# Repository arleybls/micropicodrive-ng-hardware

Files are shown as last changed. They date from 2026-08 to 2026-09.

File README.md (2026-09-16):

# MicroPicoDrive NG — Hardware

KiCad hardware design for an internal Microdrive replacement for the Sinclair QL. The device emulates a Microdrive cartridge drive using a Raspberry Pi Pico (RP2040) and stores data on a microSD card, fitting in the QL's internal Microdrive bay.

This is an evolution of [gusmanb/micropicodrive](https://github.com/gusmanb/micropicodrive) by Agustín Gimenez Bernad, who reverse-engineered the Microdrive protocol and created the original design. All credit for the core concept and the main board design goes to him.

This repository contains only the hardware. The firmware lives in a separate repository: [micropicodrive-ng-firmware](https://github.com/arleybls/micropicodrive-ng-firmware).

Fitting the board inside a QL — including the Pico and the optional vibration motor — is covered by the [hardware installation manual](docs/HARDWARE_INSTALLATION_MANUAL.md) ([PDF](docs/HARDWARE_INSTALLATION_MANUAL.pdf)). Day-to-day use, SD cards and firmware updates are in the firmware repository's manual.

## What changed in this version

The cartridge board was redesigned around a different user-interface module:

- The I²C SSD1306 OLED was replaced with a 0.96" 80×160 IPS colour display (ST7735S, 4-wire SPI) with four integrated pushbuttons (K1–K4).
- A fourth button and a blinking activity LED were added; the three separate status LEDs were removed.
- The display reset uses a passive RC circuit on the cartridge and the backlight is tied to +3.3V, so the 16-pin edge connector still carries everything with no pins to spare.

The main board is essentially the original MicroPicoDrive design, updated to KiCad 10 format with the edge-connector pinout changes required by the new cartridge.

## Boards

| Board | Folder | Description |
|---|---|---|
| MicroPicoDrive | [MicroPicoDrive/](MicroPicoDrive/) | Main controller board: Raspberry Pi Pico, 5V regulation, level shifters (SN74LVC1T45 ×2, TXU0304), QL Microdrive bus header, edge connector to the cartridge |
| MicroPicoDriveCartridge | [MicroPicoDriveCartridge/](MicroPicoDriveCartridge/) | Cartridge board: microSD socket, ST7735S SPI display with 4 buttons, activity LED, 16-pin edge connector |

Both projects are in KiCad 10 format. Custom symbol and footprint libraries are included alongside each project and referenced with relative paths, so the projects open without extra library setup.

## Assembled boards

Cartridge (left) and main board (right), front side — the cartridge's ST7735S display with the K1–K4 buttons, and the main board's level shifters, cartridge edge-connector slot, and ribbon cable to the QL:

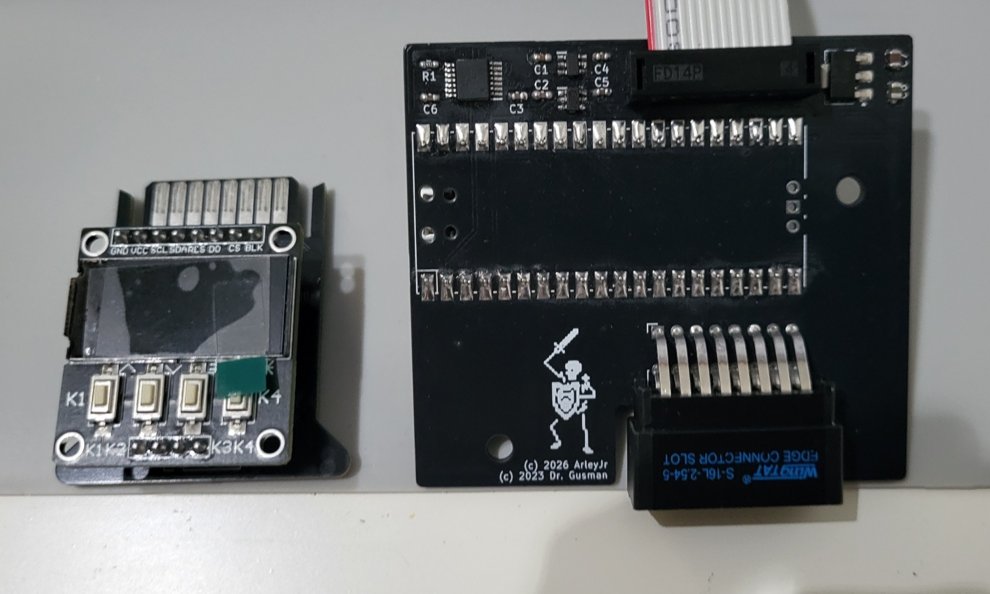
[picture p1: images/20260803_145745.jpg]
Cartridge and main board, front side


Back side — the cartridge's microSD socket, and the main board with the Raspberry Pi Pico mounted and the motor connector:

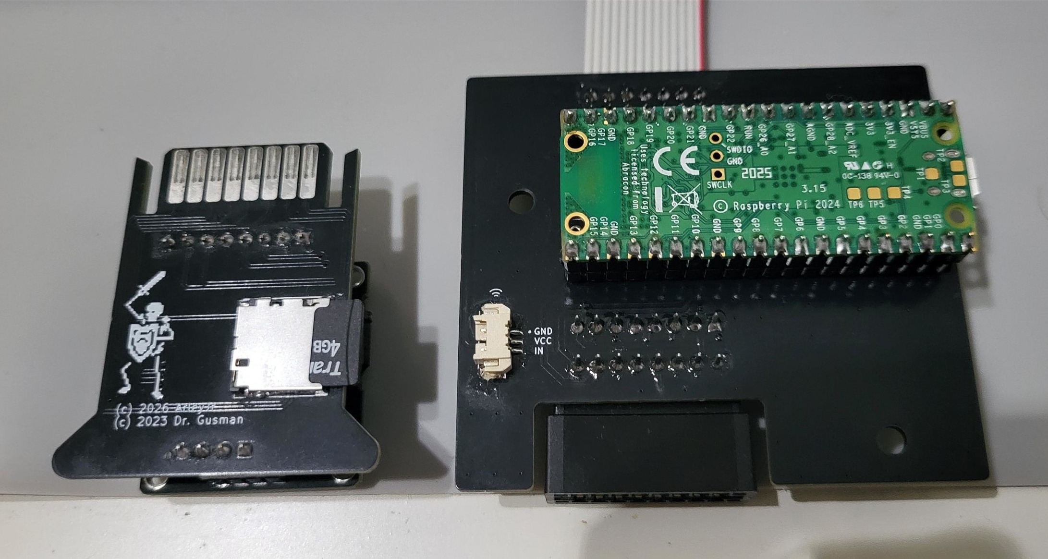
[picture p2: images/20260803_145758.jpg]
Cartridge and main board, back side


## Hot-swap guarding

The cartridge can be inserted and removed while the QL is powered, so the edge-connector fingers are staggered to enforce a safe mating order:

- **GND (pin 3) and UI_DETECT (pin 14)** are full length and make contact first. UI_DETECT is tied to GND on the cartridge, so it doubles as a second early ground contact on the opposite face of the board — a tilted insertion finds ground first on either face.
- **+3V3 (pin 1)** is retracted 1 mm and connects second.
- **All signal fingers** are retracted 1.75 mm and connect last, once the cartridge is already referenced and powered. On removal the order reverses: the signals break first while the board still has power, so an interrupted transfer fails cleanly instead of back-powering the display and SD card through their protection diodes.

UI_DETECT is read by the main board (GPIO 15, low = cartridge present). The firmware side of the guard — debouncing the detect signal on insertion before initialising the display and SD card, and tri-stating all cartridge signals on removal — is handled in [micropicodrive-ng-firmware](https://github.com/arleybls/micropicodrive-ng-firmware).

## Fabrication

Gerber and drill files are included for both boards:

- Main board: [MicroPicoDrive/gerbers/](MicroPicoDrive/gerbers/)
- Cartridge: [MicroPicoDriveCartridge/gerbers/](MicroPicoDriveCartridge/gerbers/)

A ready-to-upload JLCPCB package for the main board (Gerbers, BOM and pick-and-place for the SMD parts, with ordering notes) is in [MicroPicoDrive/jlcpcb/](MicroPicoDrive/jlcpcb/).

## Bill of materials

Interactive HTML BOMs are provided per board:

- Main board: [MicroPicoDrive/bom/ibom.html](MicroPicoDrive/bom/ibom.html)
- Cartridge: [MicroPicoDriveCartridge/bom/ibom.html](MicroPicoDriveCartridge/bom/ibom.html)

## Credits

- Original MicroPicoDrive hardware, firmware, and Microdrive protocol reverse engineering: [Agustín Gimenez Bernad (gusmanb)](https://github.com/gusmanb)
- SPI display / 4-button cartridge redesign: Arley Silveira

## License

MIT — see [LICENSE](LICENSE). The license retains the original author's copyright notice alongside the notice for the modifications in this repository.

## Related repositories

- [micropicodrive-ng-firmware](https://github.com/arleybls/micropicodrive-ng-firmware) — the firmware that brings these boards to life. It runs on the Pico mounted on the main board and answers the QL's Microdrive bus in real time, serving cartridge images from the microSD card with a menu-driven UI on the cartridge's colour display. Two builds are available: Lite for the standard Pico (RP2040) and Full for the Pico 2 W (RP2350) with Bluetooth and wireless firmware updates. Flash it to the assembled hardware and the QL sees a real Microdrive.
- [sinclair-mdv-builder](https://github.com/arleybls/sinclair-mdv-builder) — a Windows desktop tool (.NET 8 / WPF) to create, inspect, edit, and extract Sinclair QL Microdrive images (`.MDV`). Use it to author or modify cartridge images on your PC — importing files or ZIP archives while preserving QL file metadata — then copy them to the microSD card for this drive to serve to the QL.

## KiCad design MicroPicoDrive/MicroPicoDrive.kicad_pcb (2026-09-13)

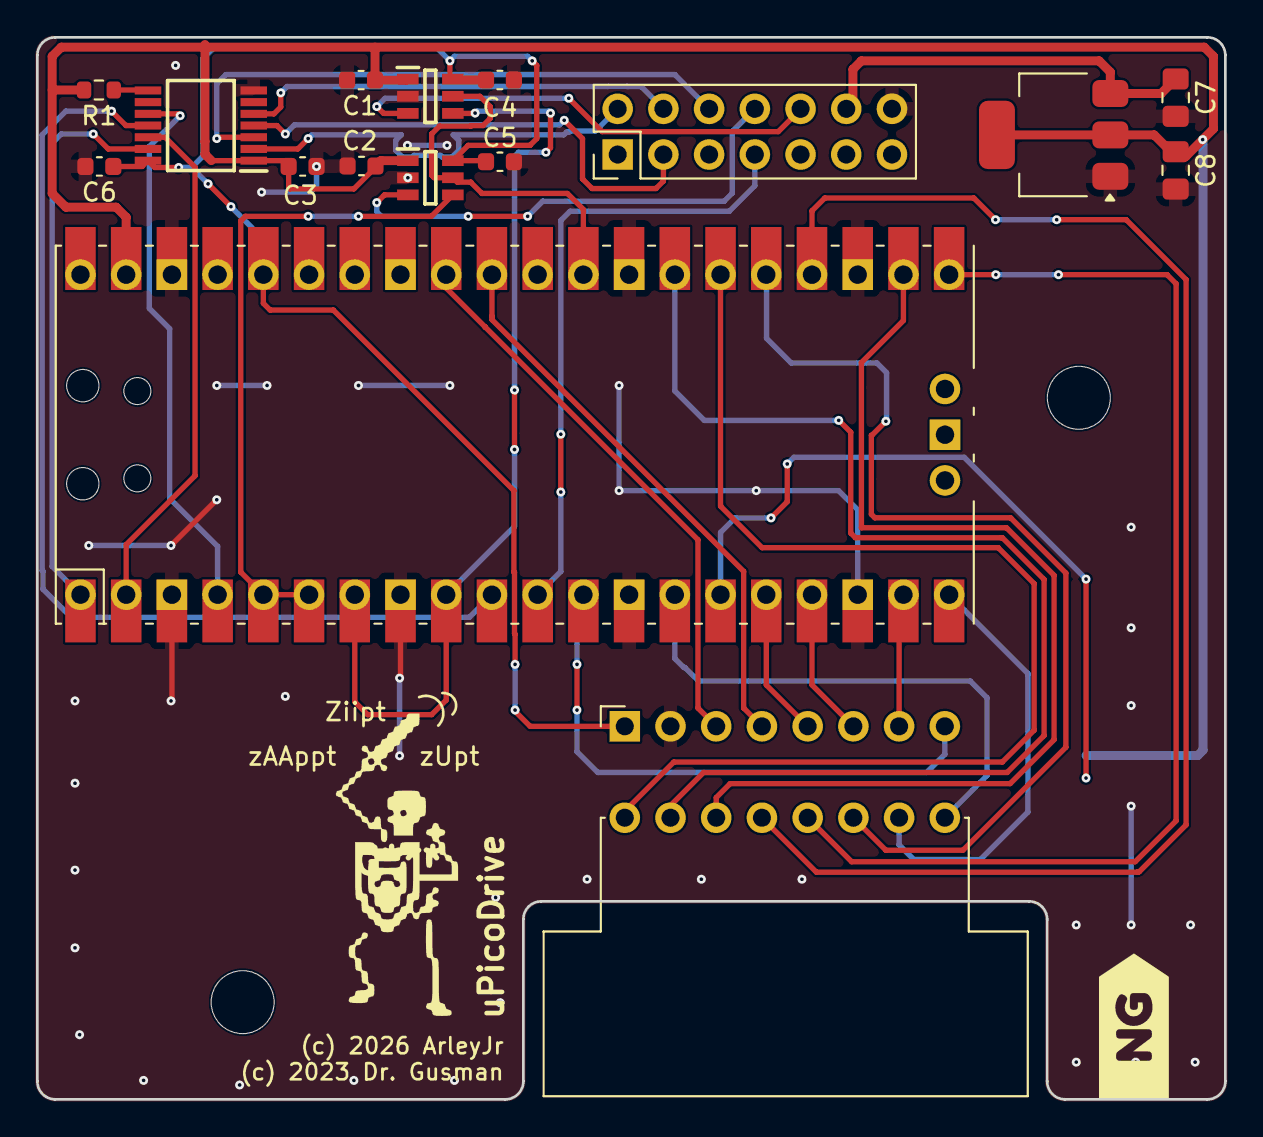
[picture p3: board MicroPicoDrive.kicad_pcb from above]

Board: 2 copper layers, 66.0 x 59.0 mm, 20 parts (1 on the bottom side), 34 nets.

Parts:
C1, C2, C3, C4, C5, C6: 100nf; C_0603_1608Metric
C7: 10uf; C_0805_2012Metric_Pad1.18x1.45mm_HandSolder
C8: 22uf; C_0805_2012Metric_Pad1.18x1.45mm_HandSolder
IC1, IC2: SN74LVC1T45DBVR; SOT95P280X145-6N
IC3: TXU0304QPWRQ1
J1: Conn_02x16; Edge_connector_02x08
J2: QL_CONN; PinHeader_2x07_P2.54mm_Vertical
J3: PicoBlade-53261-0371; PicoBlade-532610371
MH0, MH1: MountingHole_3.5mm
R1: 4k7; R_0603_1608Metric
U2: Pico; RPi_Pico_SMD_TH
U4: AMS1117-5.0; SOT-223-3_TabPin2
kibuzzard-6A718069: G***; kibuzzard-6A718069

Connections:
+3V3: C4.1, C5.1, C6.1, IC1.6 (VCCB), IC2.6 (VCCB), IC3.14 (VCCB), J1.1, U2.36 (3V3)
+5V: C1.1, C2.1, C3.1, C8.1, IC1.1 (VCCA), IC2.1 (VCCA), IC3.1 (VCCA), J3.2, R1.2, U2.39 (VSYS), U4.2 (VO)
+9V: C7.1, J2.12, U4.3 (VI)
/HEAD_DIR: IC1.5 (DIR), IC2.5 (DIR), U2.29 (GPIO22)
/PICO_CS_CK: IC3.12 (B2Y), U2.2 (GPIO1)
/PICO_CS_IN: IC3.13 (B1Y), U2.1 (GPIO0)
/PICO_CS_OUT: IC3.10 (B4), U2.4 (GPIO2)
/PICO_ERASE: J2.7, U2.11 (GPIO8)
/PICO_HEAD1: IC1.4 (B), U2.5 (GPIO3), U2.6 (GPIO4)
/PICO_HEAD2: IC2.4 (B), U2.7 (GPIO5), U2.9 (GPIO6)
/PICO_R/~W: IC3.11 (B3Y), U2.10 (GPIO7)
/QL_CS_CK: IC3.3 (A2), J2.6
/QL_CS_IN: IC3.2 (A1), J2.2
/QL_CS_OUT: IC3.5 (A4Y), J2.4
/QL_HEAD1: IC1.3 (A), J2.8
/QL_HEAD2: IC2.3 (A), J2.10
/QL_R/~W: IC3.4 (A3), J2.3
/UI_BTN_BACK: J1.9, U2.16 (GPIO12)
/UI_BTN_K4: J1.15, U2.12 (GPIO9)
/UI_BTN_NEXT: J1.11, U2.17 (GPIO13)
/UI_BTN_SELECT: J1.13, U2.19 (GPIO14)
/UI_DETECT: J1.14, U2.20 (GPIO15)
/UI_LD_ACTIVITY: J1.16, U2.14 (GPIO10)
/UI_MOTOR_IN: J3.3, U2.15 (GPIO11)
/UI_SCR_CS: J1.2, U2.26 (GPIO20)
/UI_SCR_DC: J1.4, U2.27 (GPIO21)
/UI_SCR_MOSI: J1.5, U2.32 (GPIO27_ADC1)
/UI_SCR_SCK: J1.7, U2.31 (GPIO26_ADC0)
/UI_SD_CS: J1.6, U2.22 (GPIO17)
/UI_SD_MISO: J1.10, U2.21 (GPIO16)
/UI_SD_MOSI: J1.12, U2.25 (GPIO19)
/UI_SD_SCK: J1.8, U2.24 (GPIO18)
GND: C1.2, C2.2, C3.2, C4.2, C5.2, C6.2, C7.2, C8.2, IC1.2 (GND), IC2.2 (GND), IC3.7 (GND), J1.3, J2.14, J3.1, J3.MP1, J3.MP2, U2.3 (GND), U2.8 (GND), U2.13 (GND), U2.18 (GND), U2.23 (GND), U2.28 (GND), U2.38 (GND), U4.1 (GND)
unnamed: IC3.8 (OE), R1.1

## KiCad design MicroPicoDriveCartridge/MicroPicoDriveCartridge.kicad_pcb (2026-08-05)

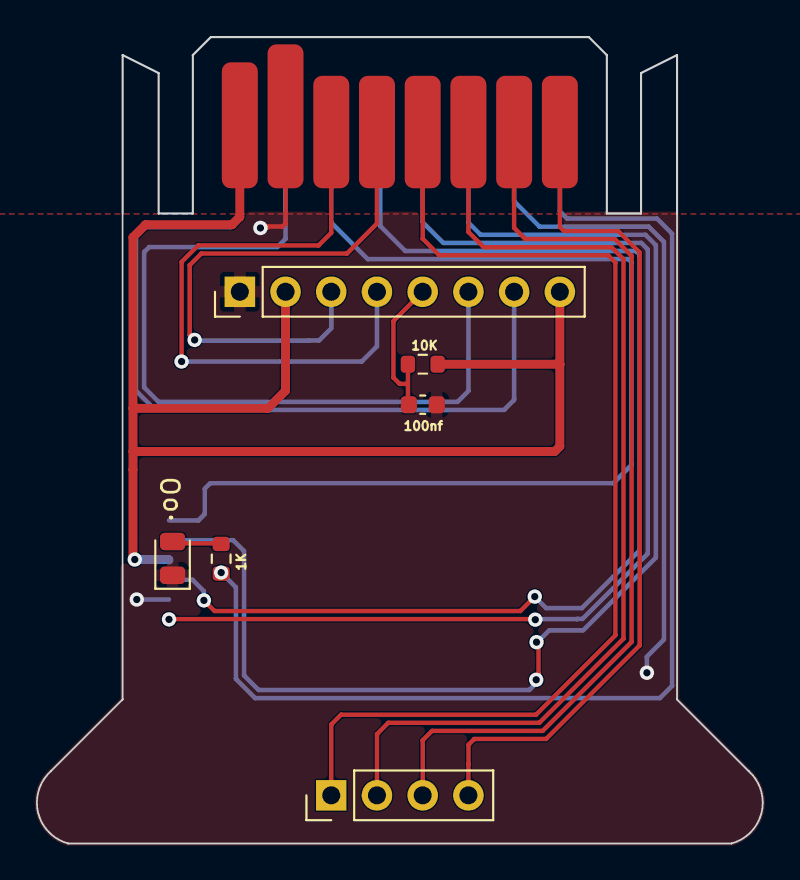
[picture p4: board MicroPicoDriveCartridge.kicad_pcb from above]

Board: 2 copper layers, 40.3 x 44.8 mm, 8 parts (1 on the bottom side), 17 nets.

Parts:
C1: 100nf; C_0603_1608Metric
D1: LED; LED_0805_2012Metric
J1: Edge Connector; MicroPicoDrive Cartridge Edge
J2: 0.96 IPS ST7735S; PinHeader_1x08_P2.54mm_Vertical
J3: K1..K4; PinHeader_1x04_P2.54mm_Vertical
J4: DM3D-SF; microSD_HC_Hirose_DM3D-SF
R1: 1K; R_0603_1608Metric
R4: 10K; R_0603_1608Metric

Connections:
+3V3: J1.1, J2.2, J2.8, J4.4 (VDD), R4.1
/UI_BTN_BACK: J1.9, J3.1
/UI_BTN_K4: J1.15, J3.4
/UI_BTN_NEXT: J1.11, J3.2
/UI_BTN_SELECT: J1.13, J3.3
/UI_LD_ACTIVITY: J1.16, R1.1
/UI_SCR_CS: J1.2, J2.7
/UI_SCR_DC: J1.4, J2.6
/UI_SCR_MOSI: J1.5, J2.4
/UI_SCR_SCK: J1.7, J2.3
/UI_SD_CS: J1.6, J4.2 (CD/DAT3)
/UI_SD_MISO: J1.10, J4.7 (DAT0)
/UI_SD_MOSI: J1.12, J4.3 (CMD)
/UI_SD_SCK: J1.8, J4.5 (CLK)
GND: C1.2, D1.1 (K), J1.3, J1.14, J2.1, J4.6 (VSS)
unnamed: D1.2 (A), R1.2
unnamed: C1.1, J2.5, R4.2

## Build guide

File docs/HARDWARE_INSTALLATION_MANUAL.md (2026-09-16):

# MicroPicoDrive NG hardware installation manual

This manual covers fitting the MicroPicoDrive NG mainboard inside a Sinclair
QL, including the Pico and the optional vibration motor. Day-to-day use, SD
card preparation, System Tools and firmware updates are covered by the
firmware manual in the
[firmware repository](https://github.com/arleybls/micropicodrive-ng-firmware).

**How complete is this guide?** The operating steps have been checked against
the firmware, and the photographs show the current NG boards, the Pico
orientation and the optional motor module. What we could not yet confirm is
the QL ribbon orientation, the mounting hardware and the exact fitting steps
for each drive bay — so treat this guide as an outline, and follow the
instructions supplied with your board revision for those details.

## The two parts and firmware versions

The **mainboard** stays inside the QL and connects to its Microdrive bus. It
carries the Raspberry Pi Pico that runs the firmware. The removable
**cartridge board** carries the display, four buttons and microSD socket.
It plugs into the mainboard's edge connector.

A **cartridge image** is a file on the microSD card that behaves like one QL
Microdrive cartridge. When you *mount* an image, the QL sees it as a cartridge
sitting in the drive; when you *eject* it, you are back in the file browser.
Mounting and ejecting happen on the screen — they are not the same thing as
physically plugging in or pulling out the cartridge board.

| Feature | Lite: Raspberry Pi Pico / RP2040 | Full: Raspberry Pi Pico 2 W / RP2350 |
|---|---|---|
| Image browsing, QL loading and saving | Yes | Yes |
| Display and motor settings | Yes | Yes |
| SD card firmware updates | UF2 file | BIN file and matching JSON manifest |
| Bluetooth file management and updates | No | Yes |
| Revert Firmware | No | When another firmware slot is available |
| BOOTSEL Mode menu entry | Yes | No |

Install the firmware that matches the Pico you actually fitted. The Pico 2 W's
wireless features use Bluetooth Low Energy (BLE), not Wi-Fi.

## Installing the mainboard in the QL

### Before opening the case

**What you'll need before you open the case:**

- The assembled mainboard and cartridge board
- The correct QL ribbon cable and mounting hardware for your kit
- A prepared microSD card

If your Pico came blank, plan to install the firmware before you close the QL
up again — see the **Firmware updates** section of the firmware manual.

1. Shut down the QL, disconnect its power supply and disconnect attached
   equipment. Remove any tape cartridges.
2. Work on a clean surface and handle the boards by their edges. Keep loose
   screws and other metal away from the electronics.
3. Open the QL using the service instructions for its case revision. Lift the
   cover carefully: the keyboard membrane tails connect it to the motherboard.
   Avoid pulling, sharply bending or trapping these tails.
4. Record the existing Microdrive cable routing and connector orientation
   before disconnecting anything.

### Fitting outline

The mainboard replaces an internal Microdrive mechanism. Its QL bus connector
is **J2**, a 14-pin (2 by 7) header. **J1** is the cartridge edge connector.
The optional motor connection is **J3**, the small three-pin socket marked
`GND`, `VCC` and `IN`. Confirm these markings against your actual board revision.

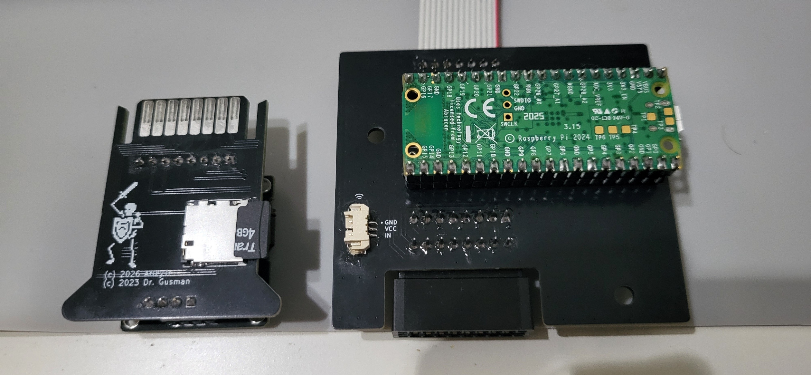
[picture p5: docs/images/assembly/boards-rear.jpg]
Rear of the NG mainboard and cartridge board, showing the Pico, J3 motor socket, edge connector and microSD socket.


### Fitting the Pico

If the mainboard was supplied without a Pico, fit the correct board before
installing the assembly in the QL. Use a Raspberry Pi Pico for Lite firmware or
a Pico 2 W for Full firmware.

1. Disconnect QL and USB power. Hold the Pico by its edges and avoid touching
   the contacts.
2. Orient it as shown below: the Pico's USB connector sits at the same end as
   the mainboard's J3 motor socket. Check the orientation before engaging any
   pins.
3. Align both rows with the sockets. Start every pin squarely, then press the
   board down evenly with light pressure at both ends. Stop if a pin bends or
   the rows do not enter together.
4. Look along both sides to confirm that no pin is outside a socket and that
   the Pico is fully and evenly seated.

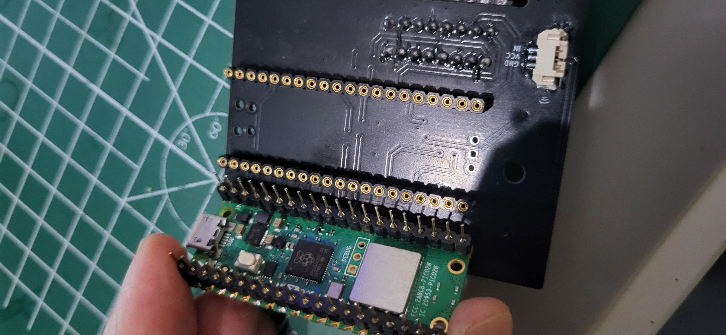
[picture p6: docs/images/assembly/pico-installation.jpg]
Aligning a Pico 2 W with the two mainboard sockets; its USB connector is beside the J3 motor socket end.


The Pico sits underneath the mainboard. That low profile is what leaves room
for the QL keyboard above it, so don't add tall headers or spacers unless your
enclosure's fitting instructions say you can.

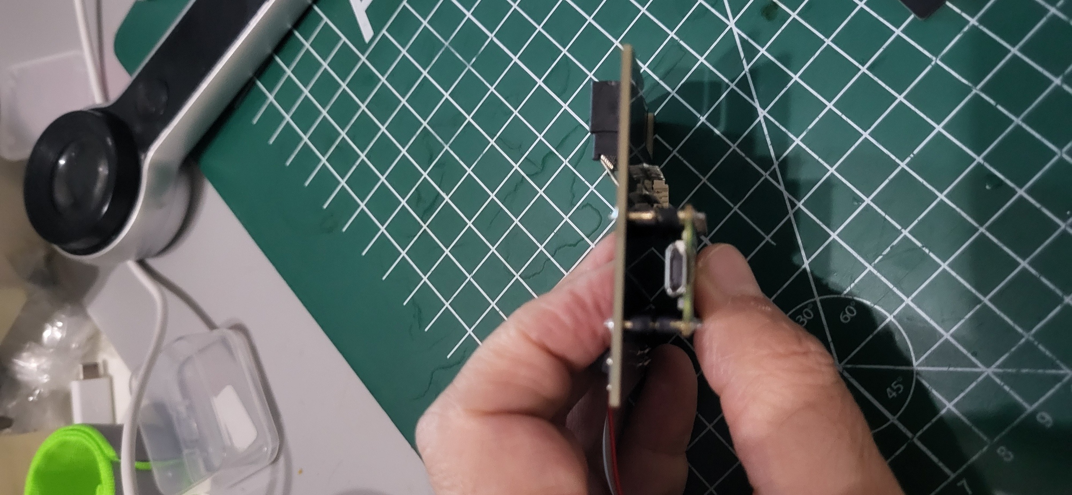
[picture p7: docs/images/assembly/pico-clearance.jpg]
Side view of the Pico mounted beneath the mainboard, showing the intended low-profile clearance.


### Installing and connecting the optional motor

Use a **driver-equipped vibration module** made for a logic-level trigger and
a 5 V supply, such as the module shown below. J3 is not a bare-motor output:
connecting a motor directly to it can overload GP11 and damage the Pico.

J3 is a three-pin Molex PicoBlade socket. Its electrical connections are:

| J3 connection | Function |
|---|---|
| GND | Ground |
| VCC | +5 V supply for the motor module |
| IN | Logic input from Pico GP11 |

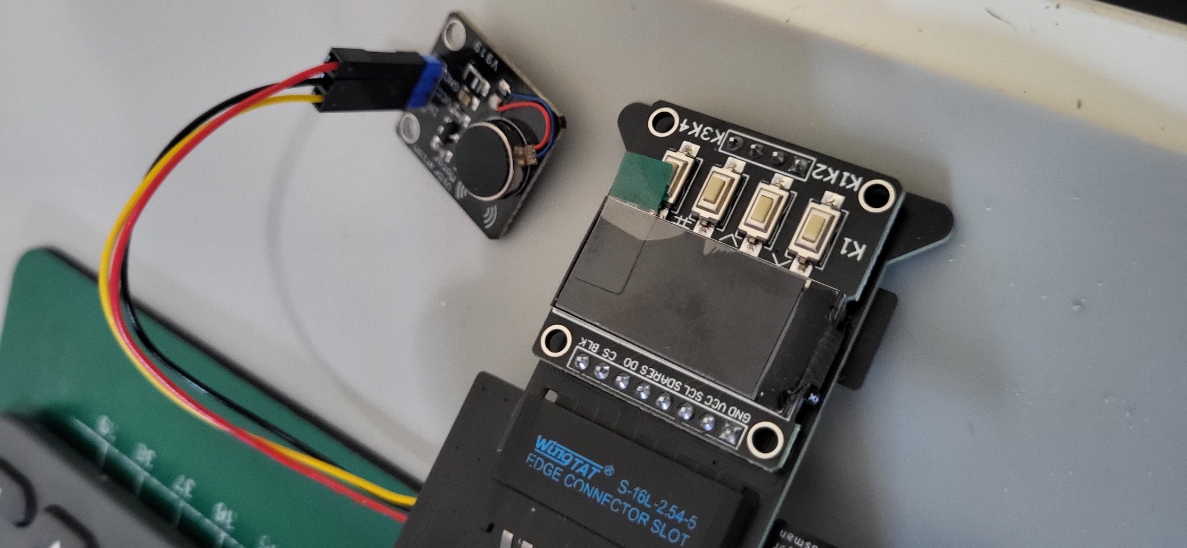
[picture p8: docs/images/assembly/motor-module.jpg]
Driver-equipped coin vibration motor module and its three-wire GND, VCC and trigger connection.


1. Disconnect QL and power it off before connecting or moving the motor.
2. Inspect the labels at both ends. Connect J3 `GND` to the module's ground,
   J3 `VCC` to its supply input, and J3 `IN` to its trigger input. Use the
   supplied keyed lead where available. **Do not rely on wire colour alone**;
   cable colours and module pin order can differ.
3. Check that the plug is fully seated and that no contact is shifted sideways.
   Keep the lead away from the cartridge opening, keyboard membrane tails,
   sharp edges and screw posts.
4. Before fixing the module permanently, close or support the keyboard safely,
   power the QL and run **System Tools > LED & Motor Test**. The motor should
   run for five seconds. Switch off and disconnect power again before adjusting it.
5. Removing the original Microdrive exposes a support hole in the lower case.
   Place the motor module over that support as shown below and align one of its
   mounting holes with the case support hole. Pass the **supplied screw** through
   the aligned holes, fit the **supplied nut** on the opposite side, and tighten
   until the module is secure. Do not overtighten: the module PCB and plastic
   support can be damaged. Check that the module lies flat and that its solder
   joints cannot touch the QL motherboard or nearby metalwork.
6. Re-run LED & Motor Test after final assembly. Configure normal feedback under
   **System Tools > Motor** as described in the firmware manual. Leave enough
   cable slack for servicing, but keep the lead out of the keyboard, cartridge
   and case-screw paths.

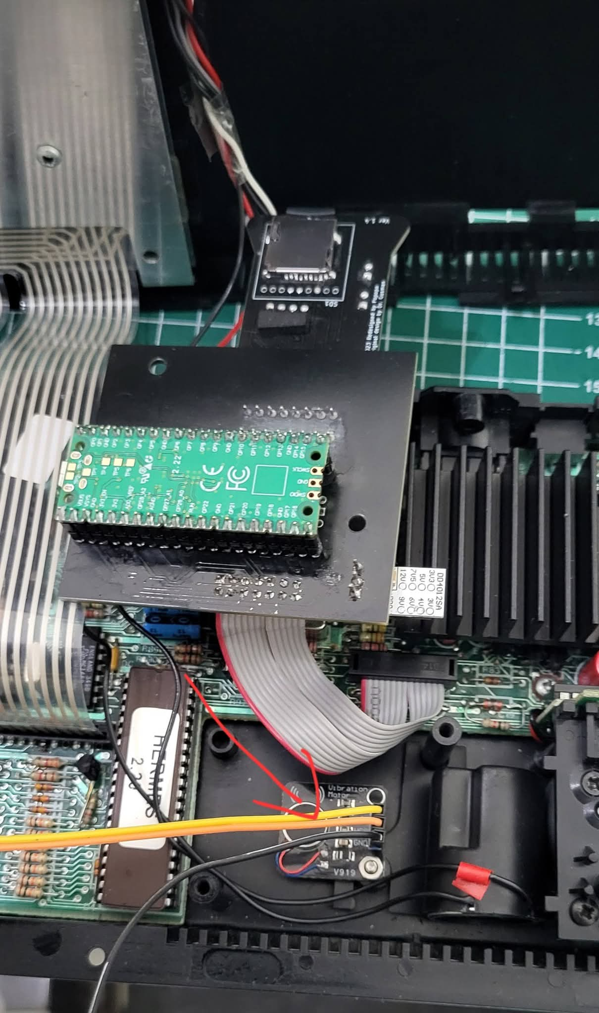
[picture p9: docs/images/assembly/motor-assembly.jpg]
Motor module secured to the lower-case support hole exposed after removing the original Microdrive, using the supplied screw and nut.


### Fitting the mainboard

1. Identify the drive position to be replaced using the kit's fitting
   instructions. The firmware has no menu setting for choosing `mdv1_` or
   `mdv2_`; numbering depends on the QL's drive-select chain and wiring.
2. Remove the selected mechanism as directed for the kit. Retain its hardware
   separately so it can be restored later.
3. Fit the mainboard with the specified supports and fasteners, with its
   cartridge connector aligned to the case opening. Check that the underside
   cannot touch conductive parts and that inserting a cartridge will not bend
   an unsupported board. Do not assume the original screws are the right length.
4. Connect the QL ribbon to J2 only after confirming pin 1 and the cable
   orientation at **both ends** against the board-specific fitting
   instructions. Check that neither connector is offset by a row or a pin.
   The stripe on the cable is not, by itself, proof of the right orientation.
5. If required, fit the Pico and optional motor as described above. Make these
   connections with power disconnected.
6. Route cables clear of case posts, sharp edges and the cartridge opening.
   Check connector seating, board clearance and the keyboard connections before
   refitting the cover.
7. Insert the prepared cartridge board without force, reconnect the QL and
   perform the first-start check described in the **First start and everyday
   use** section of the firmware manual.

Only the removable cartridge board is designed for powered insertion and
removal. Disconnect QL power before changing the mainboard, Pico, ribbon or
motor wiring. USB servicing also needs a board-specific power arrangement;
do not assume simultaneous USB and QL power is supported.

Hardware drawings, schematics and board photographs live in this repository's
board folders, `MicroPicoDrive/` and `MicroPicoDriveCartridge/`.

### If something goes wrong after reassembly

- **No display:** check cartridge-board seating and QL power. Disconnect power
  before inspecting internal ribbon or Pico connections.
- **QL cannot read the image:** wait for mounting, use the correct `mdv`
  number and try a known-good image; inspect wiring only with power
  disconnected.

See the firmware manual's Troubleshooting section for everything else.

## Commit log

2026-08-03 Initial commit: KiCad hardware for MicroPicoDrive NG
    Main board and SPI/4-button cartridge redesign, based on
    gusmanb/micropicodrive by Agustin Gimenez Bernad (MIT).
    Includes gerbers, BOM, and schematic documentation.
    [MicroPicoDrive-B_Cu.gbl, MicroPicoDrive-B_Mask.gbs, MicroPicoDrive-B_Paste.gbp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]
2026-08-03 Reorganize repository layout
    - Flatten MicroPicoDriveCartridge: project files moved up from the
    doubled inner directory
    - Move custom symbol and footprint libraries into per-board libs/
    folders and update sym-lib-table / fp-lib-table paths
    - Fix cartridge lib tables that pointed to an absolute F:/ path from
    the original author's machine; all URIs are now ${KIPRJMOD}-relative
    - Move cartridge iBOM into its board folder, regenerate it from the
    current PCB, and add the missing mainboard iBOM
    - Remove RPi_Pico.lib (legacy duplicate of RPi_Pico.kicad_sym,
    referenced nowhere)
    - Move local design notes to git-ignored docs/
    - Update README links; drop the stale-gerber warning after verifyi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
    [MicroPicoDrive-B_Cu.gbl, MicroPicoDrive-B_Mask.gbs, MicroPicoDrive-B_Paste.gbp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]
2026-08-03 Fix README BOM links after iBOM regeneration
2026-08-03 Add photos of the assembled boards to the README
2026-08-03 Constrain README board photos to 600px width
2026-08-03 Correct photo caption: motor connector, not power
2026-08-03 Stagger cartridge edge fingers for hot-swap mating order
    GND (pin 3) and the GND-tied UI_DETECT (pin 14) keep the full 8 mm
    length and mate first, +3V3 is retracted 1 mm, and all signal fingers
    are retracted 1.75 mm so they mate last and break first. Gerbers and
    iBOM regenerated; the Edge library footprint is synced with the board.
    [MicroPicoDriveCartridge-B_Cu.gbl, MicroPicoDriveCartridge-B_Mask.gbs, MicroPicoDriveCartridge-B_Paste.gbp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]
2026-08-05 Add mainboard silkscreen labels and cartridge copper zone
    Mainboard gains front-silkscreen labelling (KiBuzzard label and text
    items); the cartridge PCB gets a new copper pour. Gerbers re-exported
    for both boards.
    [MicroPicoDrive-B_Cu.gbl, MicroPicoDrive-B_Mask.gbs, MicroPicoDrive-B_Paste.gbp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]
2026-09-13 Change C7 and C8 to 0805 hand-solder footprints
    The two capacitors move from C_0603_1608Metric to
    C_0805_2012Metric_Pad1.18x1.45mm_HandSolder in both the schematic
    and the board. Gerbers and drill files are regenerated from the
    updated board, and the DRC silkscreen text height, thickness and
    back-layer mirroring checks are set to ignore.
    [MicroPicoDrive-B_Cu.gbl, MicroPicoDrive-B_Mask.gbs, MicroPicoDrive-B_Paste.gbp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]
2026-09-16 Hardware installation manual
    Moved from the firmware repository: the fitting guide (case opening,
    Pico, optional vibration motor, mainboard and ribbon) with its
    assembly photographs, normalized to strip misleading EXIF rotation
    flags, plus the PDF renderer and a README pointer. The firmware
    repository keeps the firmware manual; each manual references the
    other.

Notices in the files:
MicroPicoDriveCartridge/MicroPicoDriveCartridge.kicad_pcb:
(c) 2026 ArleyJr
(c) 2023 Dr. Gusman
